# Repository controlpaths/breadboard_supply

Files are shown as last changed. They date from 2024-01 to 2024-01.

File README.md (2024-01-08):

# Breadboard Power supply

This tiny board generates all the voltages needed for your signal processing designs. 

This board features a bipolar power supply and a single voltage power supply for control.

The bipolar power supply is managed by a [TPS65131](https://www.ti.com/product/es-mx/TPS65131). A split-rail converter with a maximum output current of 750 mA. The outputs of this power supply is configured for -12 V and +13 volts. 

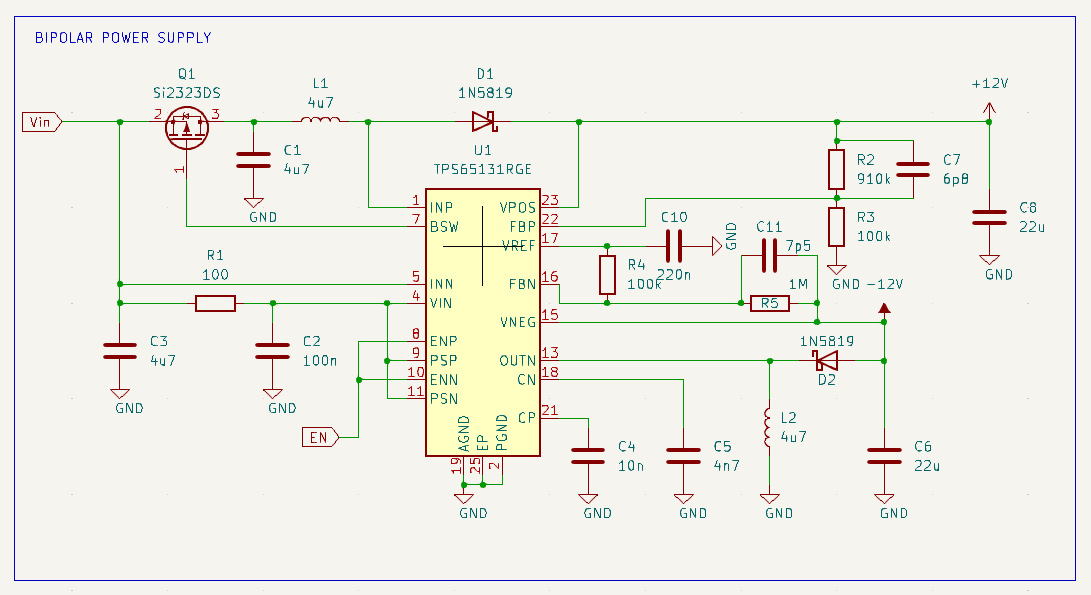
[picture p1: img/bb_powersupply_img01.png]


The board also has a 3v3 volts, 1 Amp output generated by an NCP1529.

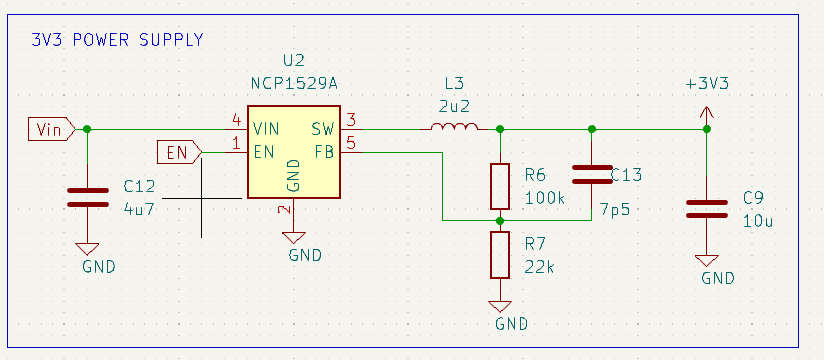
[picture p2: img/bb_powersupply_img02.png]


All the power rails as well as the the enable input and the input voltage are connected through a 2.54mm right angle connector ready to be inserted into a breadboard. 

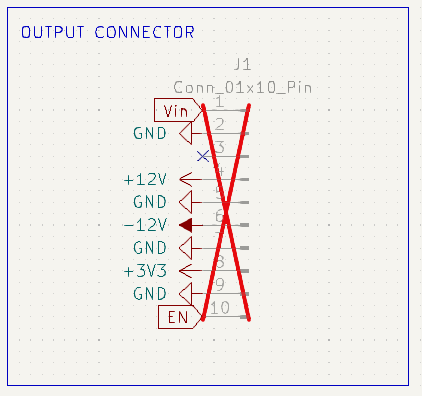
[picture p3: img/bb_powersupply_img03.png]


## Galery

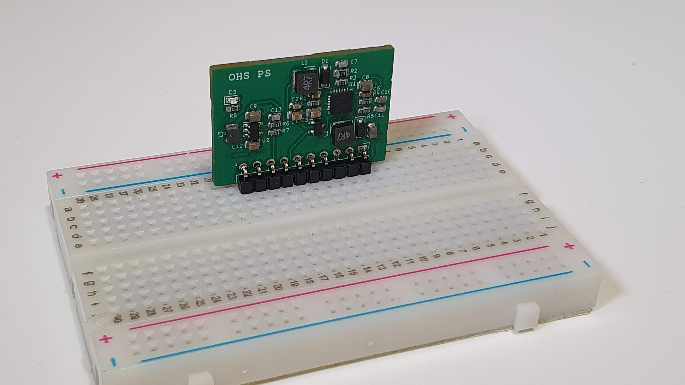
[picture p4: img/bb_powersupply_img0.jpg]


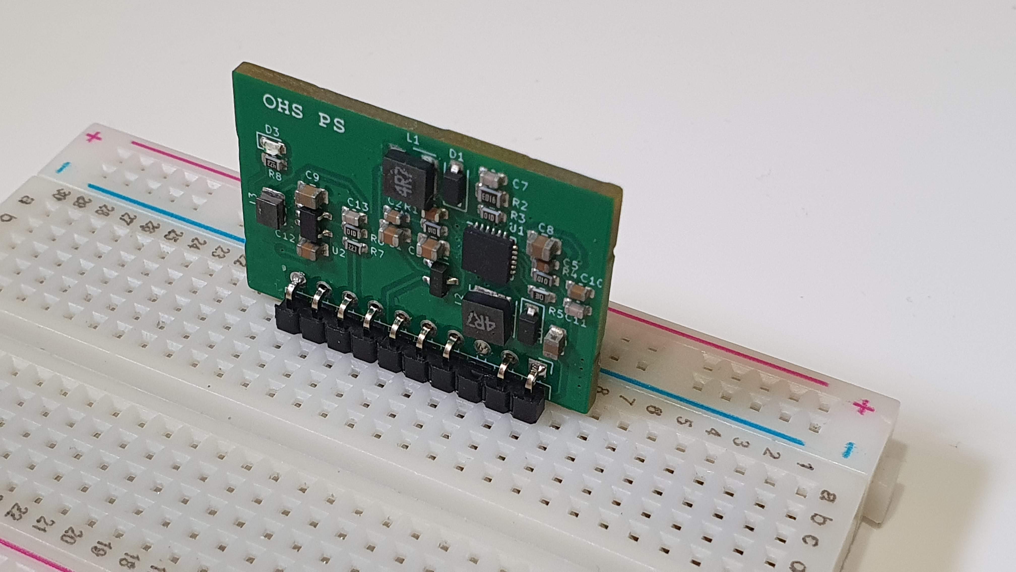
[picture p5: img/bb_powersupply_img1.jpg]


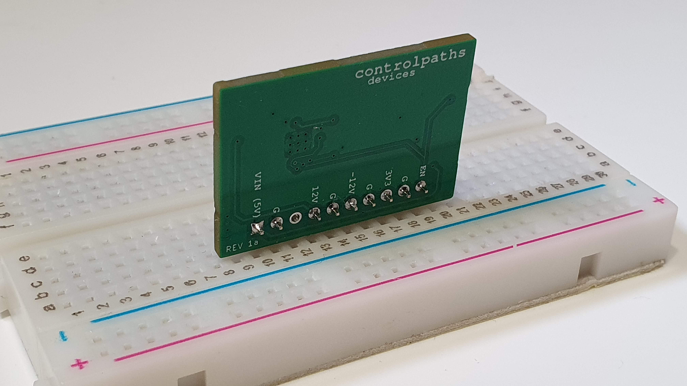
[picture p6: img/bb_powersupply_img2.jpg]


## Get yours

This board is open-source, so if you want to get yours, you can use the [output_files](./kicad/output_files/) to manufacture your own in [JLCPCB](https://jlcpcb.com/?from=controlpath). You just need to compress the file of the [output_files](./kicad/output_files/) and upload it to [JLCPCB](https://jlcpcb.com/?from=controlpath)

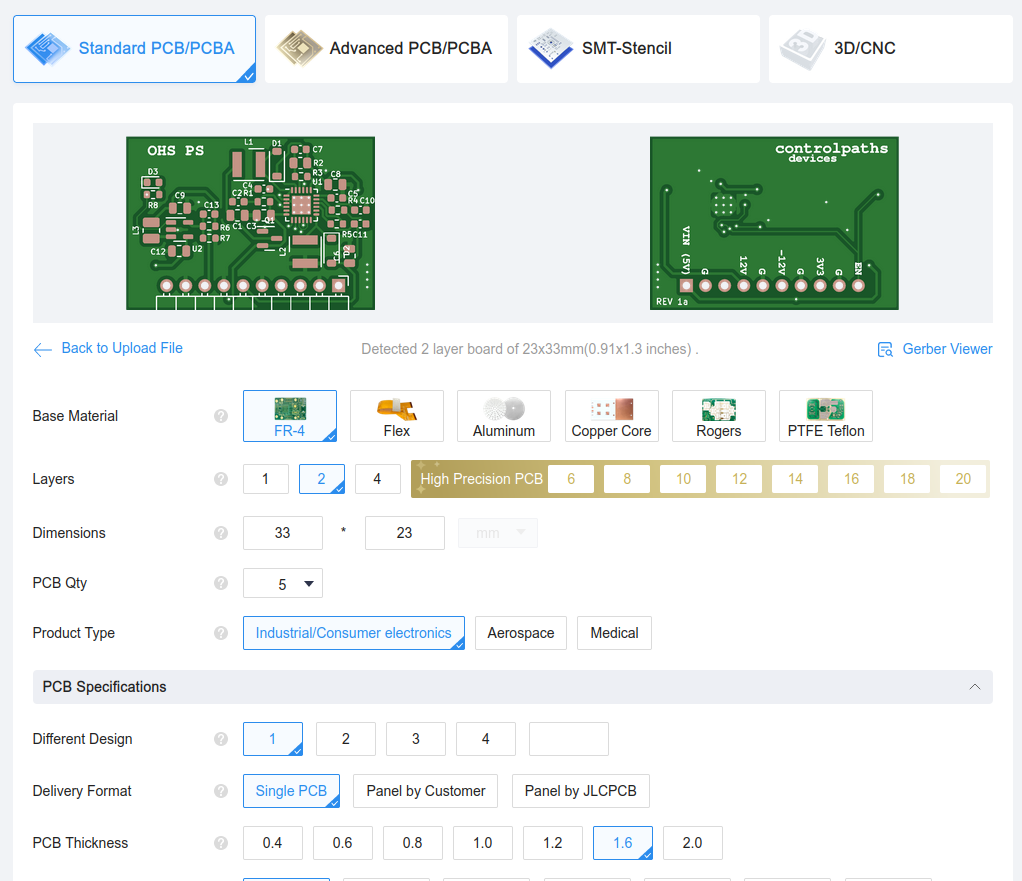
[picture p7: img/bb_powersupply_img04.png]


Remember to change the Surface Finish to LeadFree HASL to make your board ROHS compliant.

Also, they can assemble your board using the [centroid](./kicad/output_files/ohe_power_supply_1-all-pos.csv) file and the [BOM](./kicad/output_files/bom.csv) file, which are also available in this repository. Doing this, in a few days you will receive in your home some of these boards.

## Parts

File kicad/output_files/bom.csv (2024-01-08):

# | Reference | Qty | Value | Footprint | DNP | JLCPCB Part #
1 | C1, C3, C12 | 3 | 4u7 | Capacitor_SMD:C_0805_2012Metric
2 | C2 | 1 | 100n | Capacitor_SMD:C_0603_1608Metric
3 | C4 | 1 | 10n | Capacitor_SMD:C_0603_1608Metric
4 | C5 | 1 | 4n7 | Capacitor_SMD:C_0603_1608Metric
5 | C6, C8 | 2 | 22u | Capacitor_SMD:C_0805_2012Metric
6 | C7 | 1 | 6p8 | Capacitor_SMD:C_0603_1608Metric
7 | C9 | 1 | 10u | Capacitor_SMD:C_0805_2012Metric
8 | C10 | 1 | 220n | Capacitor_SMD:C_0603_1608Metric
9 | C11, C13 | 2 | 7p5 | Capacitor_SMD:C_0603_1608Metric
10 | D1, D2 | 2 | 1N5819 | Diode_SMD:D_SOD-123 |  | C82544
11 | D3 | 1 | LED | LED_SMD:LED_0603_1608Metric
12 | J1 | 1 | Conn_01x10_Pin | Connector_PinHeader_2.54mm:PinHeader_1x10_P2.54mm_Horizontal | DNP
13 | L1, L2 | 2 | 4u7 | Inductor_SMD_Wurth:L_Wurth_WE-LQSH-4020 |  | C2649331
14 | L3 | 1 | 2u2 | Inductor_SMD:L_1008_2520Metric |  | C668447
15 | Q1 | 1 | Si2323DS | Package_TO_SOT_SMD:SOT-23 |  | C165449
16 | R1 | 1 | 100 | Resistor_SMD:R_0603_1608Metric
17 | R2 | 1 | 910k | Resistor_SMD:R_0805_2012Metric |  | C425483
18 | R3, R4, R6 | 3 | 100k | Resistor_SMD:R_0603_1608Metric
19 | R5 | 1 | 1M | Resistor_SMD:R_0603_1608Metric
20 | R7 | 1 | 22k | Resistor_SMD:R_0603_1608Metric
21 | R8 | 1 | 4k7 | Resistor_SMD:R_0603_1608Metric
22 | U1 | 1 | TPS65131RGE | Package_DFN_QFN:VQFN-24-1EP_4x4mm_P0.5mm_EP2.45x2.45mm_ThermalVias |  | C87663
23 | U2 | 1 | NCP1529A | Package_TO_SOT_SMD:SOT-23-5

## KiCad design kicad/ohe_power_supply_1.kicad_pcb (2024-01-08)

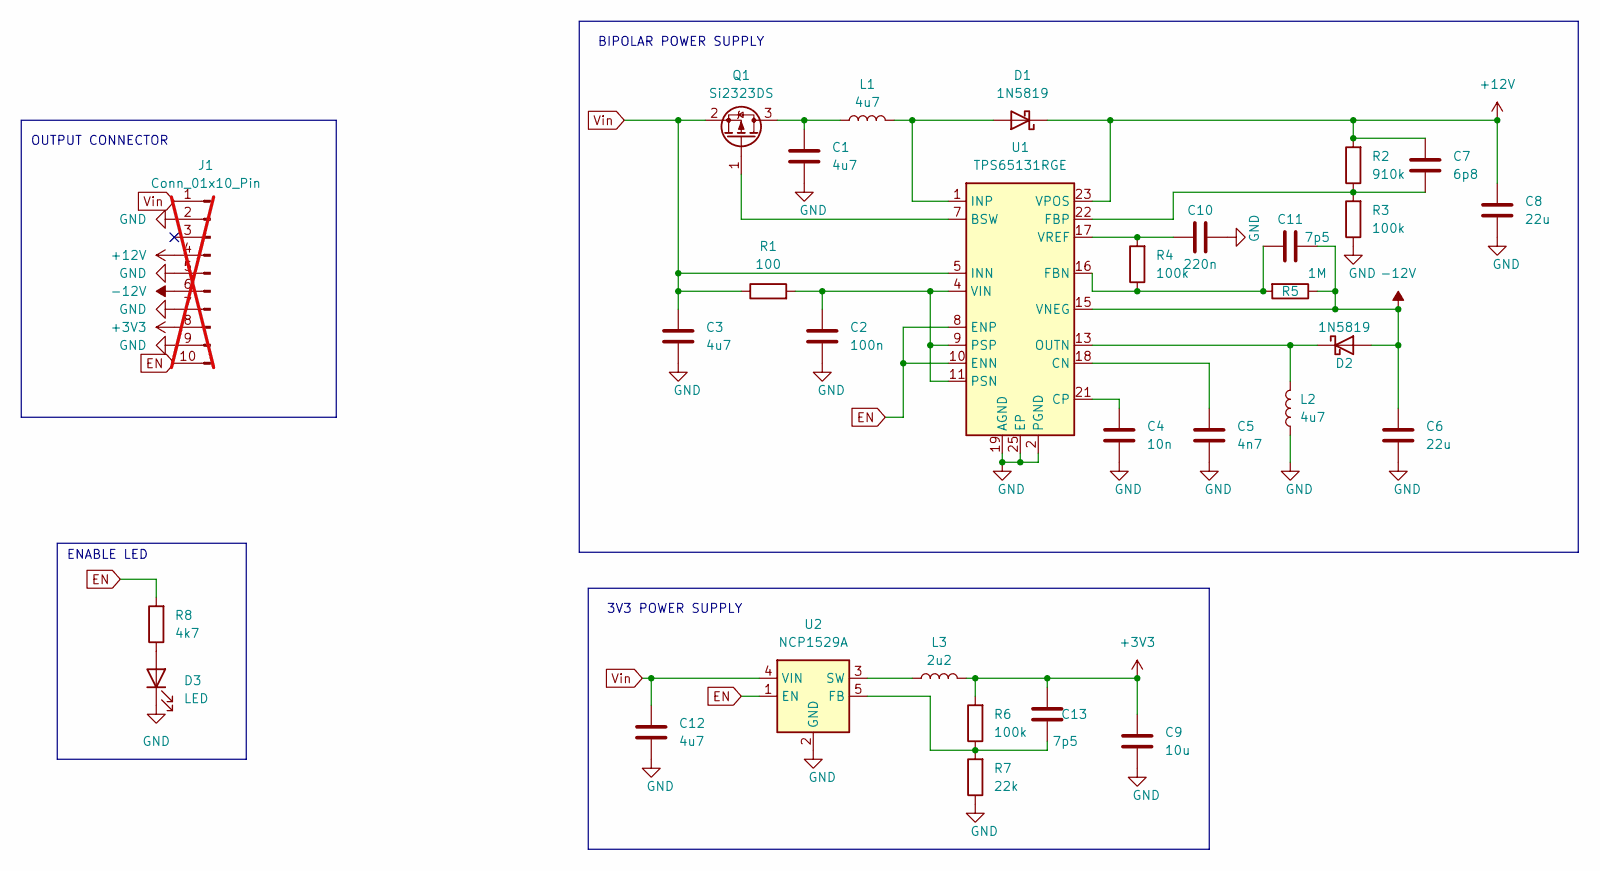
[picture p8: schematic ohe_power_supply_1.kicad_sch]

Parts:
C1, C3, C12: 4u7; C_0805_2012Metric
C2: 100n; C_0603_1608Metric
C4: 10n; C_0603_1608Metric
C5: 4n7; C_0603_1608Metric
C6, C8: 22u; C_0805_2012Metric
C7: 6p8; C_0603_1608Metric
C9: 10u; C_0805_2012Metric; JLCPCB Part # C307523
C10: 220n; C_0603_1608Metric
C11, C13: 7p5; C_0603_1608Metric
D1, D2: 1N5819; D_SOD-123; JLCPCB Part # C82544
D3: LED; LED_0603_1608Metric
J1: Conn_01x10_Pin; PinHeader_1x10_P2.54mm_Horizontal; not fitted
L1, L2: 4u7; L_Wurth_WE-LQSH-4020; JLCPCB Part # C2649331
L3: 2u2; L_1008_2520Metric; JLCPCB Part # C668447
Q1: Si2323DS; SOT-23; JLCPCB Part # C165449
R1: 100; R_0603_1608Metric
R2: 910k; R_0805_2012Metric; JLCPCB Part # C425483
R3, R4, R6: 100k; R_0603_1608Metric
R5: 1M; R_0603_1608Metric
R7: 22k; R_0603_1608Metric
R8: 4k7; R_0603_1608Metric
U1: TPS65131RGE; VQFN-24-1EP_4x4mm_P0.5mm_EP2.45x2.45mm_ThermalVias; JLCPCB Part # C87663
U2: NCP1529A; SOT-23-5

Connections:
+3V3: C9.1, C13.1, J1.8, L3.2, R6.2
+12V: C7.1, C8.1, D1.1 (K), J1.4, R2.2, U1.23 (VPOS)
-12V: C6.1, C11.2, D2.2 (A), J1.6, R5.1, U1.15 (VNEG)
EN: J1.10, R8.2, U1.8 (ENP), U1.10 (ENN), U2.1 (EN)
GND: C1.2, C2.2, C3.2, C4.2, C5.2, C6.2, C8.2, C9.2, C10.2, C12.2, D3.1 (K), J1.2, J1.5, J1.7, J1.9, L2.1, R3.1, R7.1, U1.2 (PGND), U1.3 (PGND), U1.19 (AGND), U1.25 (EP), U2.2 (GND)
unnamed: D1.2 (A), L1.2, U1.1 (INP), U1.24 (INP)
unnamed: D2.1 (K), L2.2, U1.13 (OUTN), U1.14 (OUTN)
unnamed: D3.2 (A), R8.1
unnamed: C1.1, L1.1, Q1.3 (D)
unnamed: Q1.1 (G), U1.7 (BSW)
unnamed: C5.1, U1.18 (CN)
unnamed: C4.1, U1.21 (CP)
unnamed: C11.1, R4.1, R5.2, U1.16 (FBN)
unnamed: C7.2, R2.1, R3.2, U1.22 (FBP)
unnamed: C2.1, R1.2, U1.4 (VIN), U1.9 (PSP), U1.11 (PSN)
unnamed: C10.1, R4.2, U1.17 (VREF)
unnamed: C13.2, R6.1, R7.2, U2.5 (FB)
unnamed: L3.1, U2.3 (SW)
Vin: C3.1, C12.1, J1.1, Q1.2 (S), R1.1, U1.5 (INN), U1.6 (INN), U2.4 (VIN)

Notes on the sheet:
3V3 POWER SUPPLY
ENABLE LED
OUTPUT CONNECTOR
BIPOLAR POWER SUPPLY

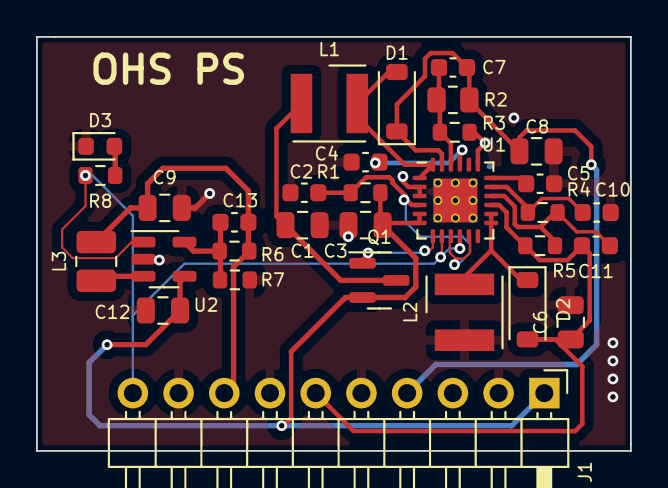
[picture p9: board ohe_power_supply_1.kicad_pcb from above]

Board: 2 copper layers, 33.0 x 23.0 mm, 31 parts (0 on the bottom side), 19 nets.
